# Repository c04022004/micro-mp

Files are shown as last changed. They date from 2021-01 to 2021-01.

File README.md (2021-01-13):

# Multi-purpose Arduino Micro shield

This is an attempt stuff functionalities onto an ATmega32U4-based board while keeping a moderate footprint and simple low-cost parts. The original version is made out of the necessity to replace dupont(jumper) wires for stability. The board gradually expanded into the current form. This is also my first few PCBs, so expect it to be less than optimal. I learnt a lot going through the design, soldering, debug process and enjoyed working on it.

## Functionalities/Devices
- 0.96'/1.3' OLED monitor
- RS485 thru MAX485
- Dual USB Serial (Native+CP2102)
- WS2812 LED, expandable, physical off SW
- EEPROM (ATMEL AT24C )
- PCF8574 I/O expansion (8 Pins)
- Type-C USB Power, fuse
- Buttons, Reset button
- IDC header (2x05) for external boards

## Renderings
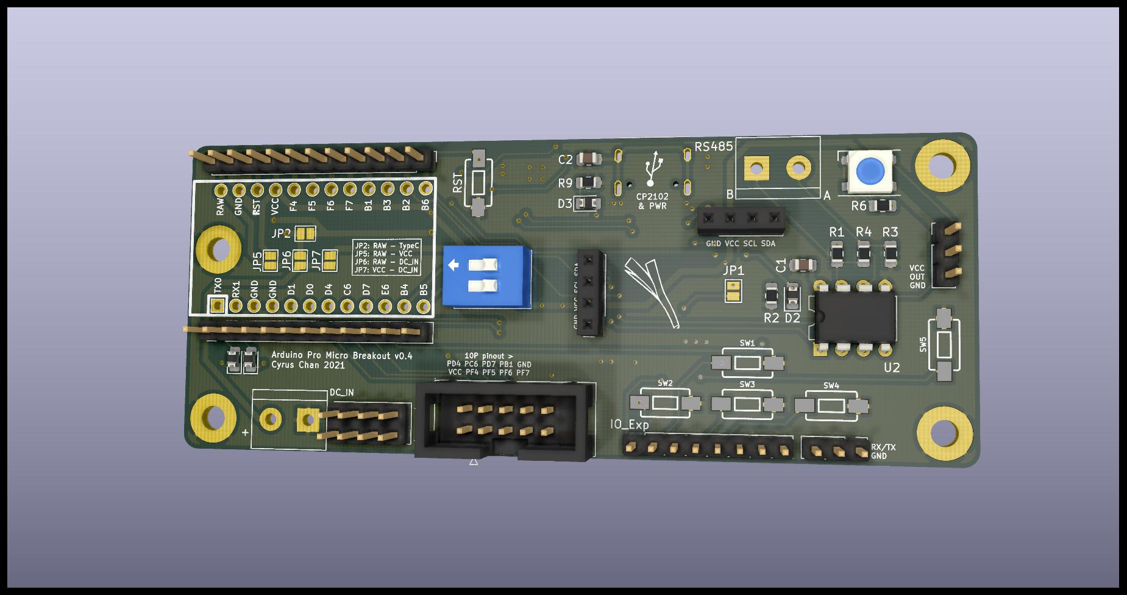
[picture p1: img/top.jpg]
Top Side

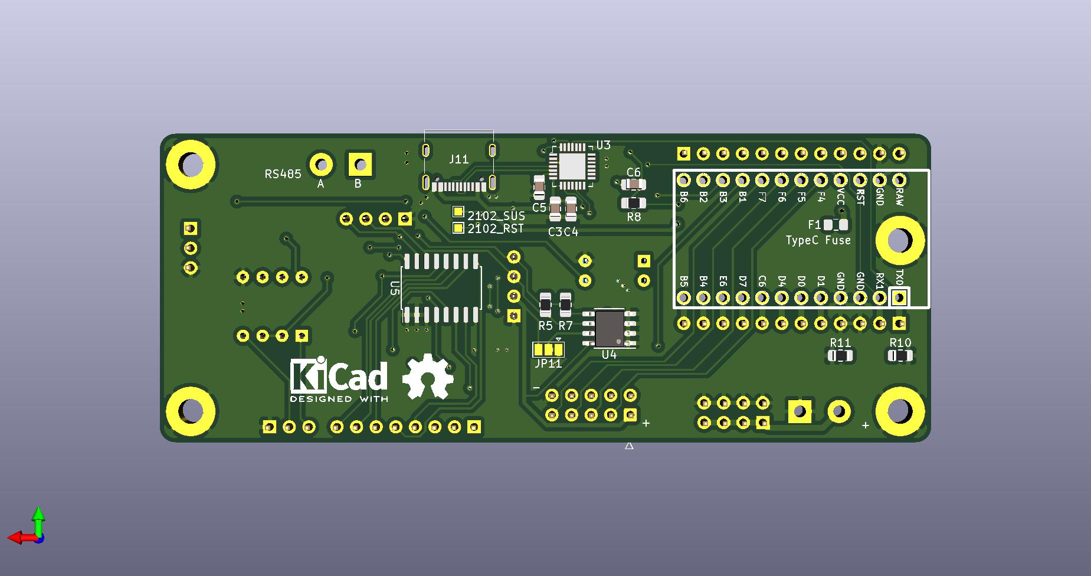
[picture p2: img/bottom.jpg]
Bottom Side


## Actual Hardware
Evolving Hardware:  
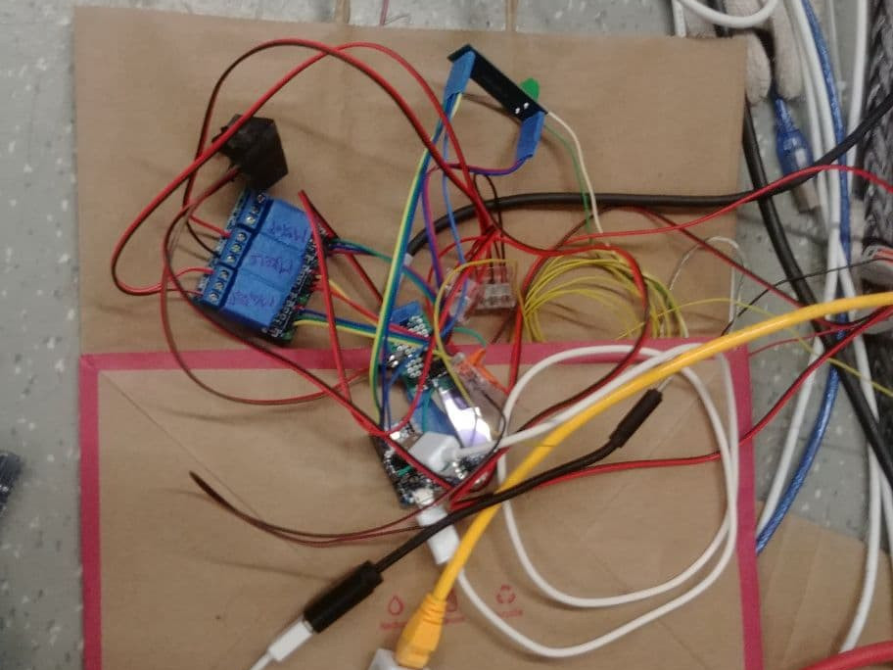
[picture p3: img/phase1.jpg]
Phase1

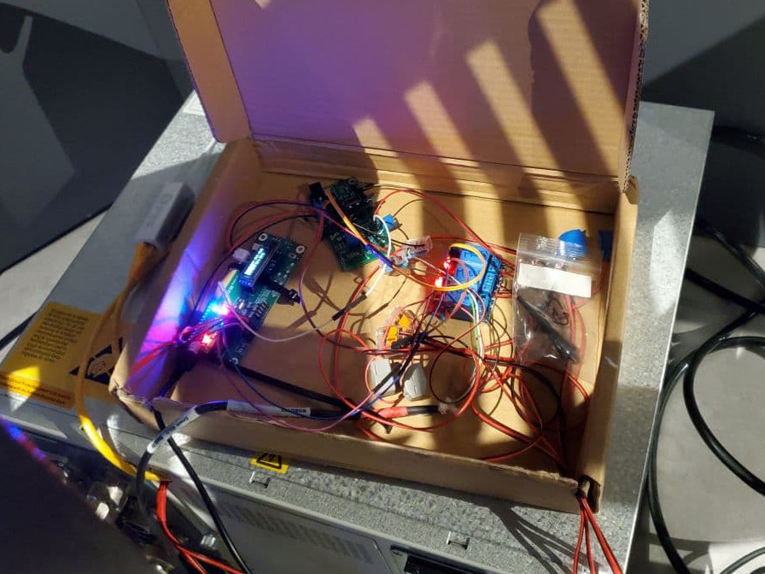
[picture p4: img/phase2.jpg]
Phase2

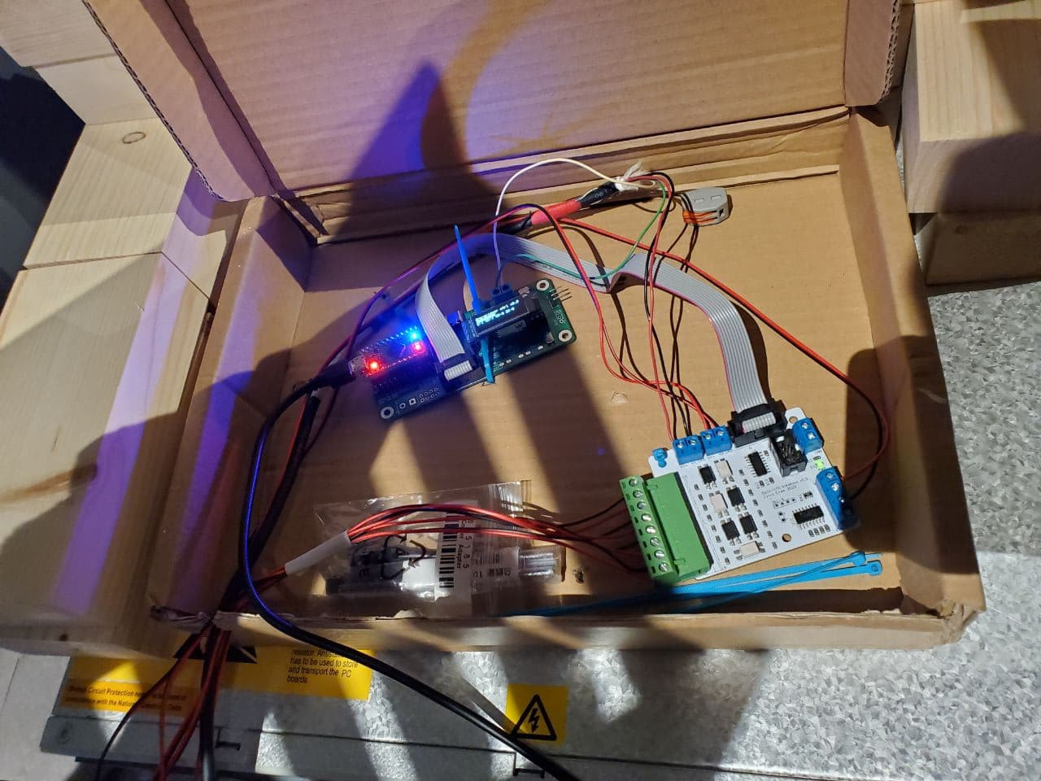
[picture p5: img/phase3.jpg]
Phase3


## Library Used
- https://github.com/keebio/keebio-components
- https://github.com/keebio/Keebio-Parts.pretty
- https://github.com/sparkfun/SparkFun-KiCad-Libraries
- https://github.com/Digi-Key/digikey-kicad-library

## To be constructed
- BOM
- Demo Images
- Extensions

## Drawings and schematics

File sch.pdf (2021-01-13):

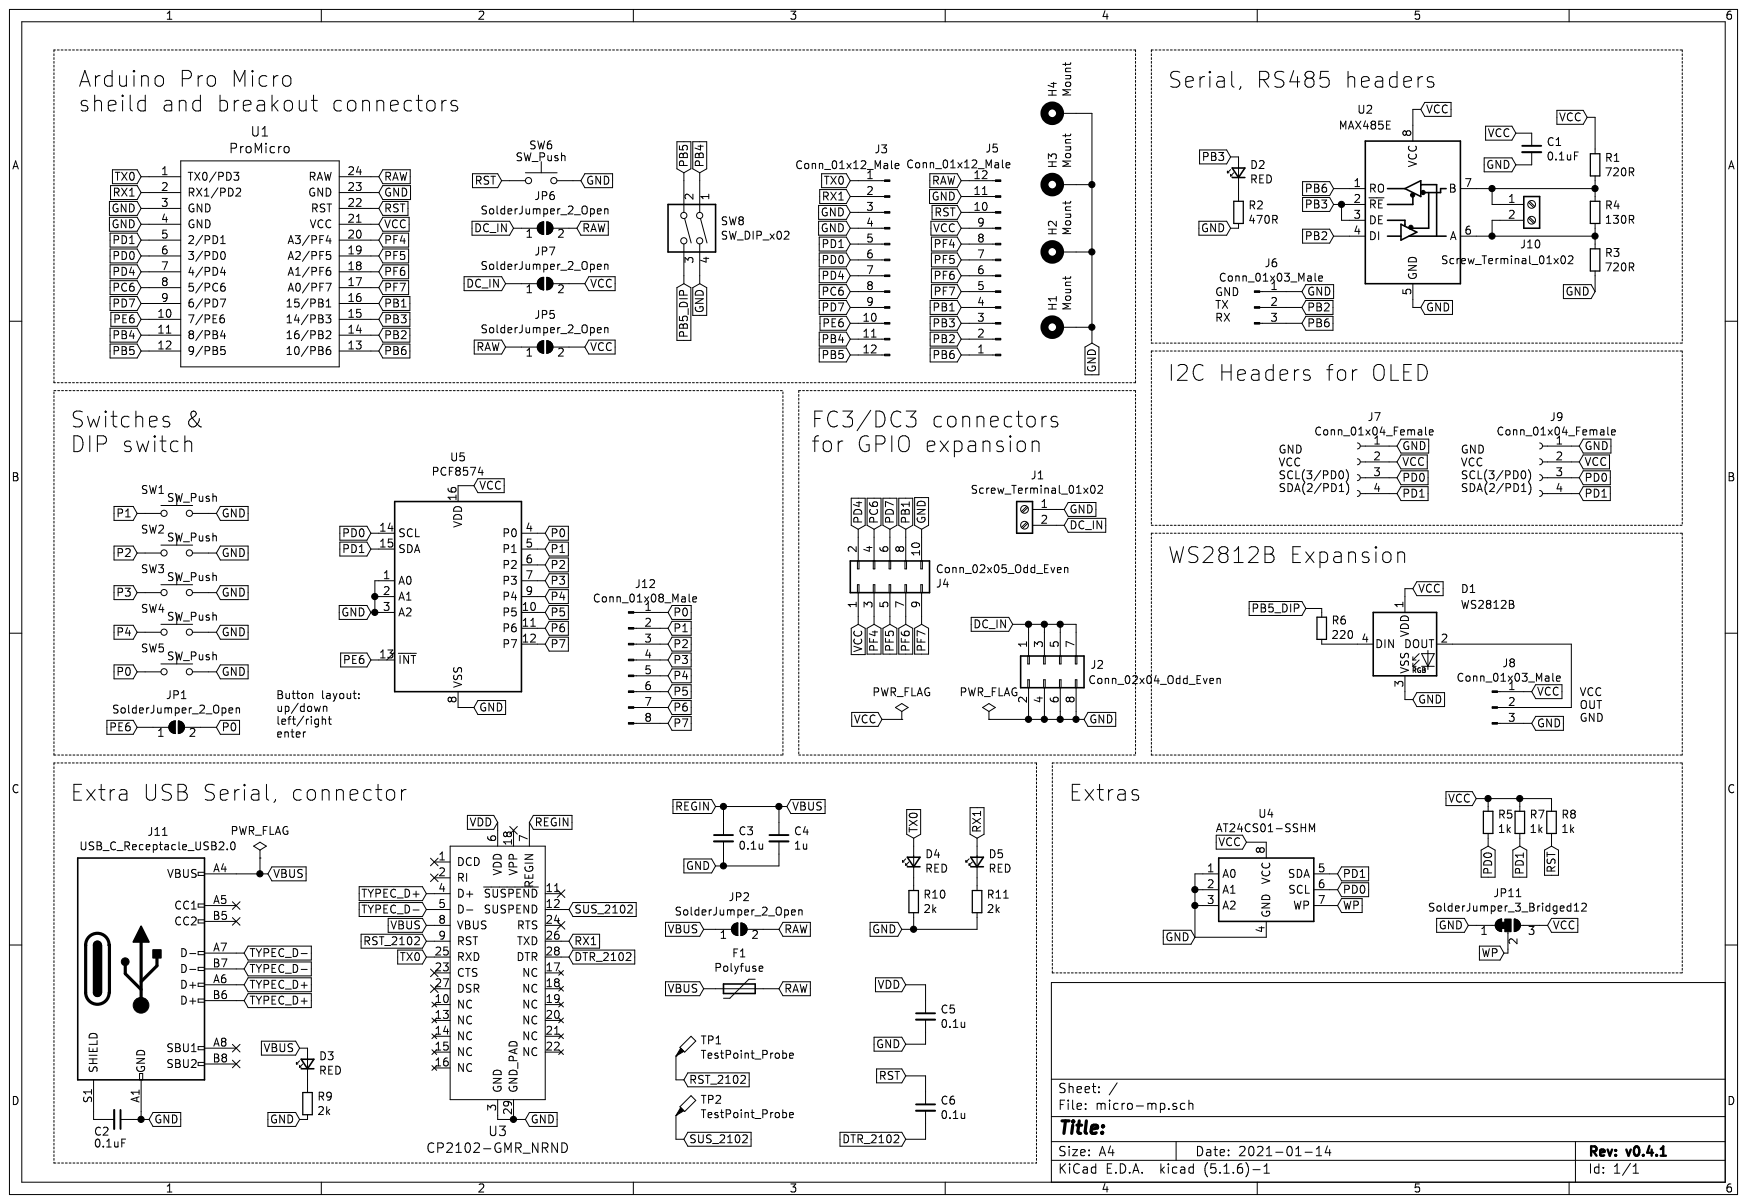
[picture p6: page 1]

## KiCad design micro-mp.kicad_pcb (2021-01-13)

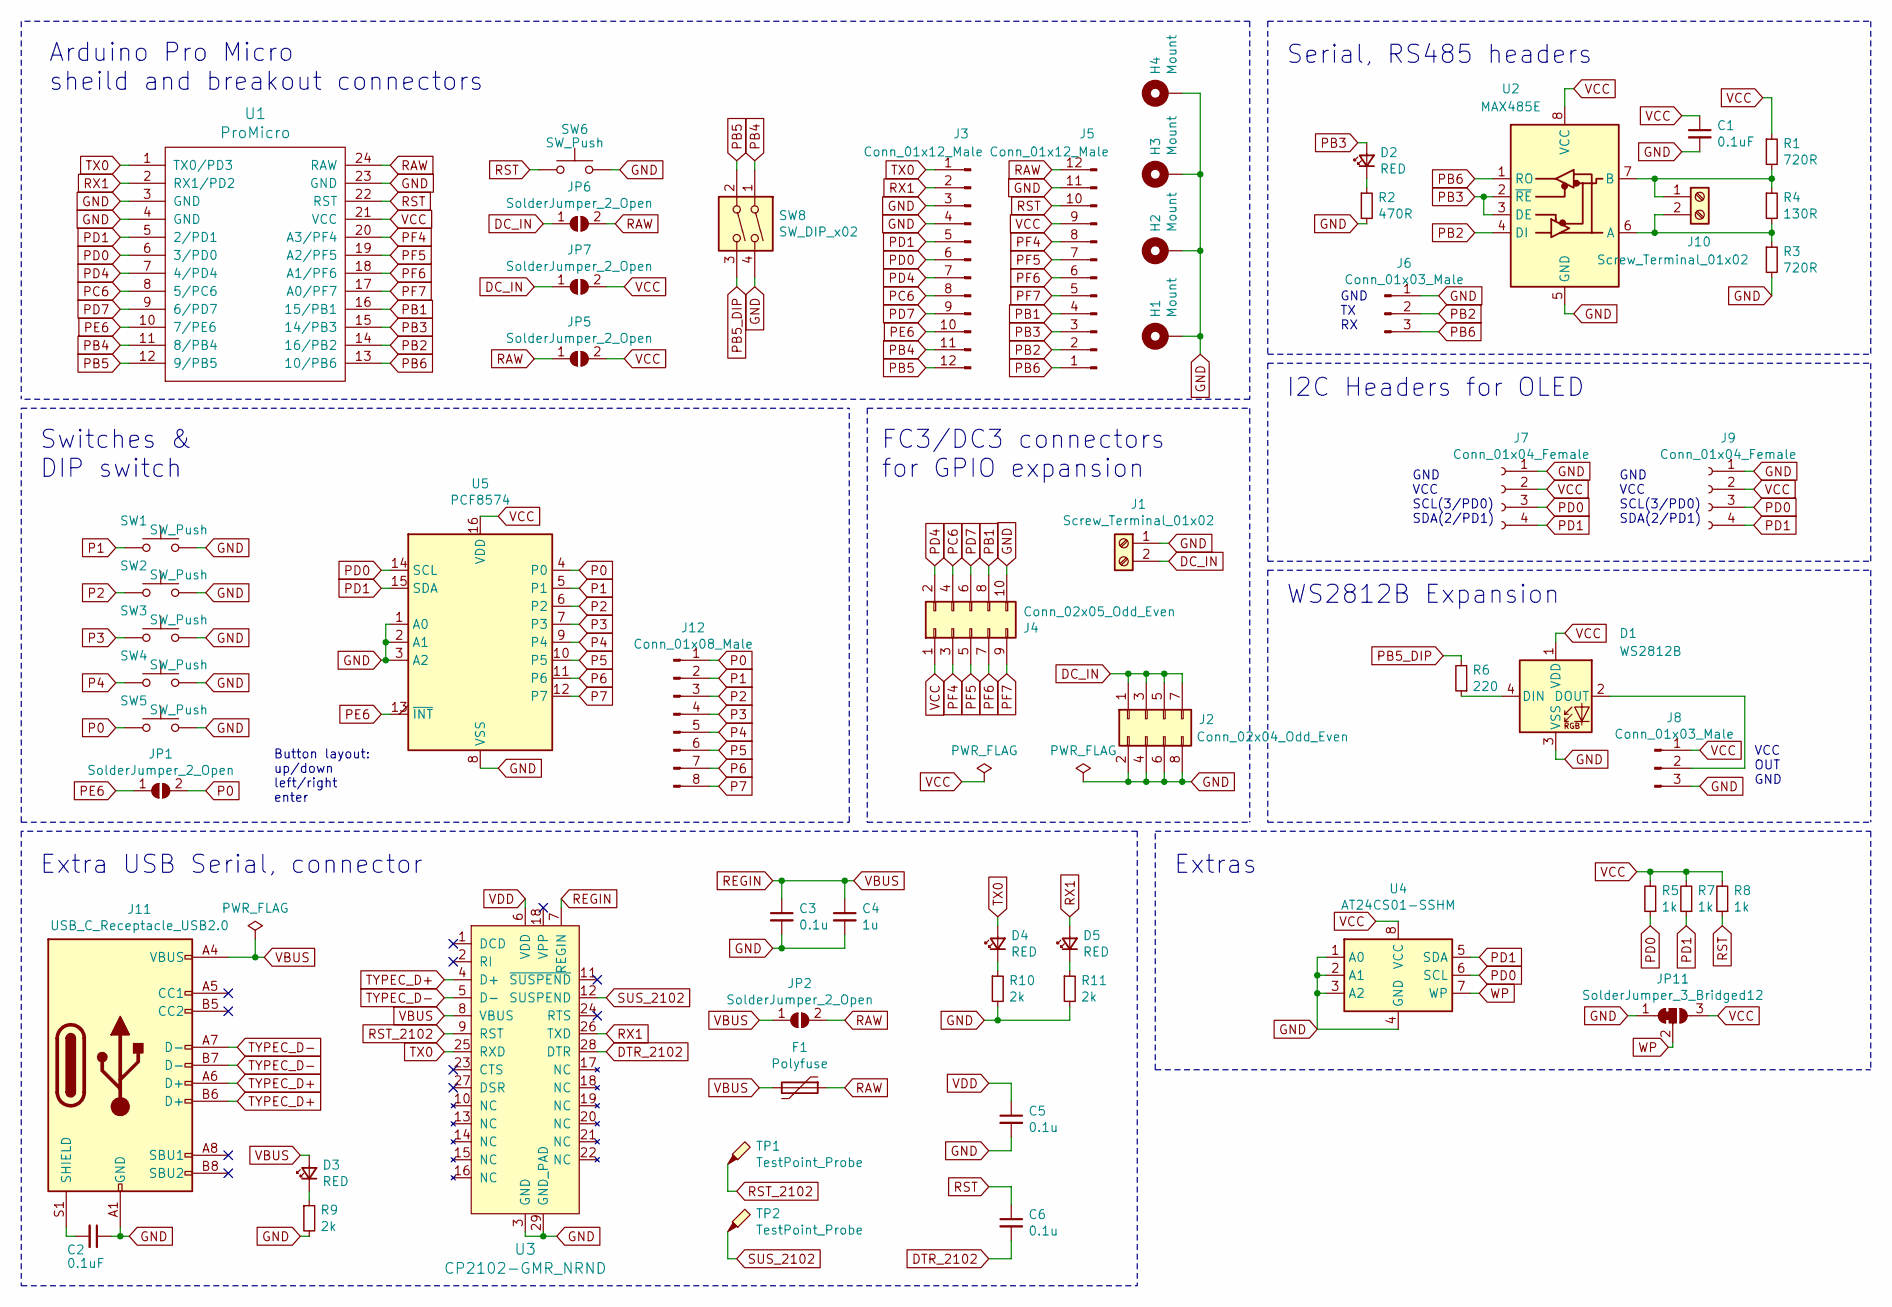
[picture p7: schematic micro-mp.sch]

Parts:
C1, C2: 0.1uF; C_0805_2012Metric_Pad1.15x1.40mm_HandSolder
C3, C5, C6: 0.1u; C_0805_2012Metric_Pad1.15x1.40mm_HandSolder
C4: 1u; C_0805_2012Metric_Pad1.15x1.40mm_HandSolder
D1: WS2812B; LED_WS2812B_PLCC4_5.0x5.0mm_P3.2mm
D2, D3, D4, D5: RED; D_0805_2012Metric_Pad1.15x1.40mm_HandSolder
F1: Polyfuse; Fuse_0805_2012Metric_Pad1.15x1.40mm_HandSolder
H1, H2, H3, H4: Mount; MountingHole_3.2mm_M3_Pad
J1, J10: Screw_Terminal_01x02; TerminalBlock_bornier-2_P5.08mm
J2: Conn_02x04_Odd_Even; PinHeader_2x04_P2.54mm_Vertical
J3, J5: Conn_01x12_Male; PinHeader_1x12_P2.54mm_Vertical
J4: Conn_02x05_Odd_Even; IDC-Header_2x05_P2.54mm_Vertical
J6, J8: Conn_01x03_Male; PinHeader_1x03_P2.54mm_Vertical
J7, J9: Conn_01x04_Female; PinSocket_1x04_P2.54mm_Vertical
J11: USB_C_Receptacle_USB2.0; USB_C_Receptacle_Palconn_UTC16-G
J12: Conn_01x08_Male; PinHeader_1x08_P2.54mm_Vertical
JP1, JP2, JP5, JP6, JP7: SolderJumper_2_Open; SolderJumper-2_P1.3mm_Open_Pad1.0x1.5mm
JP11: SolderJumper_3_Bridged12; SolderJumper-3_P1.3mm_Bridged12_Pad1.0x1.5mm
R1, R3: 720R; R_0805_2012Metric_Pad1.15x1.40mm_HandSolder
R2: 470R; R_0805_2012Metric_Pad1.15x1.40mm_HandSolder
R4: 130R; R_0805_2012Metric_Pad1.15x1.40mm_HandSolder
R5, R7, R8: 1k; R_0805_2012Metric_Pad1.15x1.40mm_HandSolder
R6: 220; R_0805_2012Metric_Pad1.15x1.40mm_HandSolder
R9, R10, R11: 2k; R_0805_2012Metric_Pad1.15x1.40mm_HandSolder
SW1, SW2, SW3, SW4, SW5, SW6: SW_Push; TACTILE_SWITCH_SMD_6.0X3.5MM
SW8: SW_DIP_x02; SW_DIP_SPSTx02_Slide_9.78x7.26mm_W7.62mm_P2.54mm
TP1, TP2: TestPoint_Probe; TestPoint_Pad_1.0x1.0mm
U1: ProMicro; ArduinoProMicro
U2: MAX485E; DIP-8_W7.62mm
U3: CP2102-GMR_NRND; VFQFN-28-1EP_5x5mm; MPN CP2102-GMR; Digi-Key_PN 336-1160-1-ND
U4: AT24CS01-SSHM; SOIC-8_3.9x4.9mm_P1.27mm
U5: PCF8574; SO-16_5.3x10.2mm_P1.27mm

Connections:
DC_IN: J1.2, J2.1, J2.3, J2.5, J2.7, JP6.1 (A), JP7.1 (A)
DTR_2102: C6.2, U3.28 (DTR)
GND: C1.2, C2.1, C3.2, C4.2, C5.2, D1.3 (VSS), H1.1, H2.1, H3.1, H4.1, J1.1, J2.2, J2.4, J2.6, J2.8, J3.3, J3.4, J4.10, J5.11, J6.1, J7.1, J8.3, J9.1, J11.A1 (GND), J11.A12 (GND), J11.B1 (GND), J11.B12 (GND), JP11.1 (A), R2.2, R3.2, R9.2, R10.2, R11.2, SW1.2, SW2.2, SW3.2, SW4.2, SW5.2, SW6.2, SW8.4, U1.3 (GND), U1.4 (GND), U1.23 (GND), U2.5 (GND), U3.3 (GND), U3.29 (GND_PAD), U4.1 (A0), U4.2 (A1), U4.3 (A2), U4.4 (GND), U5.1 (A0), U5.2 (A1), U5.3 (A2), U5.8 (VSS)
unnamed: C2.2, J11.S1 (SHIELD)
unnamed: D1.2 (DOUT), J8.2
unnamed: D1.4 (DIN), R6.1
unnamed: D2.1 (K), R2.1
unnamed: D3.1 (K), R9.1
unnamed: D4.1 (K), R10.1
unnamed: D5.1 (K), R11.1
unnamed: J10.1, R1.2, R4.1, U2.7 (B)
unnamed: J10.2, R3.1, R4.2, U2.6 (A)
P0: J12.1, JP1.2 (B), SW5.1, U5.4 (P0)
P1: J12.2, SW1.1, U5.5 (P1)
P2: J12.3, SW2.1, U5.6 (P2)
P3: J12.4, SW3.1, U5.7 (P3)
P4: J12.5, SW4.1, U5.9 (P4)
P5: J12.6, U5.10 (P5)
P6: J12.7, U5.11 (P6)
P7: J12.8, U5.12 (P7)
PB1: J4.8, J5.4, U1.16 (15/PB1)
PB2: J5.2, J6.2, U1.14 (16/PB2), U2.4 (DI)
PB3: D2.2 (A), J5.3, U1.15 (14/PB3), U2.2 (~RE), U2.3 (DE)
PB4: J3.11, SW8.1, U1.11 (8/PB4)
PB5: J3.12, SW8.2, U1.12 (9/PB5)
PB5_DIP: R6.2, SW8.3
PB6: J5.1, J6.3, U1.13 (10/PB6), U2.1 (RO)
PC6: J3.8, J4.4, U1.8 (5/PC6)
PD0: J3.6, J7.3, J9.3, R5.1, U1.6 (3/PD0), U4.6 (SCL), U5.14 (SCL)
PD1: J3.5, J7.4, J9.4, R7.1, U1.5 (2/PD1), U4.5 (SDA), U5.15 (SDA)
PD4: J3.7, J4.2, U1.7 (4/PD4)
PD7: J3.9, J4.6, U1.9 (6/PD7)
PE6: J3.10, JP1.1 (A), U1.10 (7/PE6), U5.13 (~INT~)
PF4: J4.3, J5.8, U1.20 (A3/PF4)
PF5: J4.5, J5.7, U1.19 (A2/PF5)
PF6: J4.7, J5.6, U1.18 (A1/PF6)
PF7: J4.9, J5.5, U1.17 (A0/PF7)
RAW: F1.1, J5.12, JP2.2 (B), JP5.1 (A), JP6.2 (B), U1.24 (RAW)
REGIN: C3.1, C4.1, D3.2 (A), F1.2, J11.A4 (VBUS), J11.A9 (VBUS), J11.B4 (VBUS), J11.B9 (VBUS), JP2.1 (A), U3.7 (REGIN), U3.8 (VBUS)
RST: C6.1, J5.10, R8.1, SW6.1, U1.22 (RST)
RST_2102: TP1.1, U3.9 (RST)
RX1: D5.2 (A), J3.2, U1.2 (RX1/PD2), U3.26 (TXD)
SUS_2102: TP2.1, U3.12 (SUSPEND)
TX0: D4.2 (A), J3.1, U1.1 (TX0/PD3), U3.25 (RXD)
TYPEC_D+: J11.A6 (D+), J11.B6 (D+), U3.4 (D+)
TYPEC_D-: J11.A7 (D-), J11.B7 (D-), U3.5 (D-)
VCC: C1.1, D1.1 (VDD), J4.1, J5.9, J7.2, J8.1, J9.2, JP5.2 (B), JP7.2 (B), JP11.3 (B), R1.1, R5.2, R7.2, R8.2, U1.21 (VCC), U2.8 (VCC), U4.8 (VCC), U5.16 (VDD)
VDD: C5.1, U3.6 (VDD)
WP: JP11.2 (C), U4.7 (WP)

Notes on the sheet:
GND TX RX
GND VCC SCL(3/PD0) SDA(2/PD1)
Button layout: up/down left/right enter
Serial, RS485 headers
I2C Headers for OLED
Extra USB Serial, connector
VCC OUT GND
WS2812B Expansion
Switches & DIP switch
Arduino Pro Micro sheild and breakout connectors
FC3/DC3 connectors for GPIO expansion
Extras

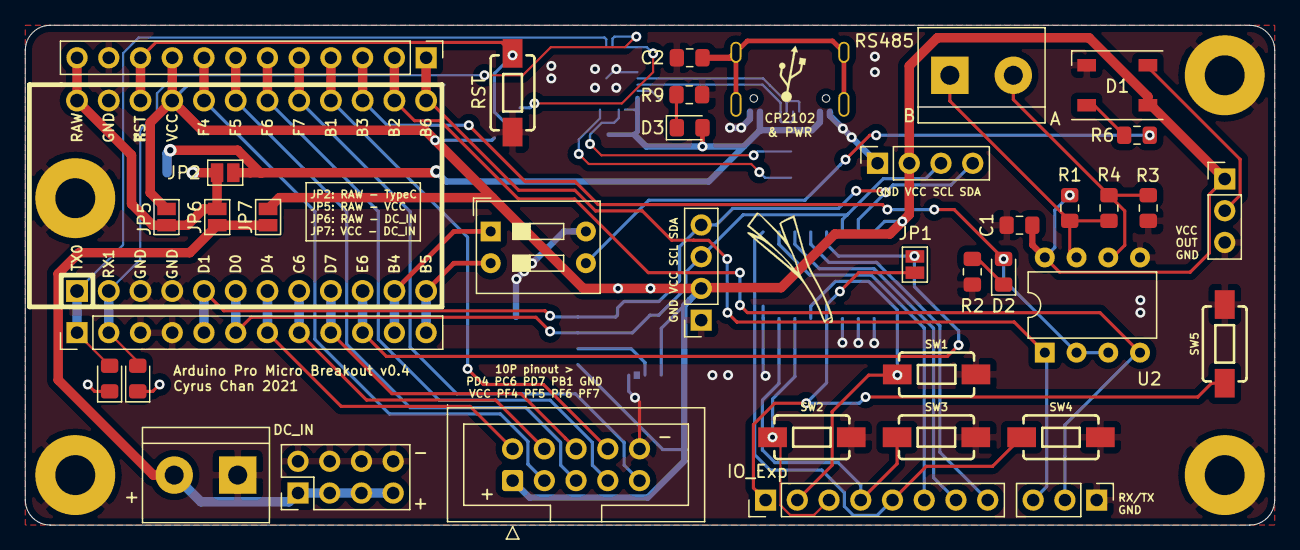
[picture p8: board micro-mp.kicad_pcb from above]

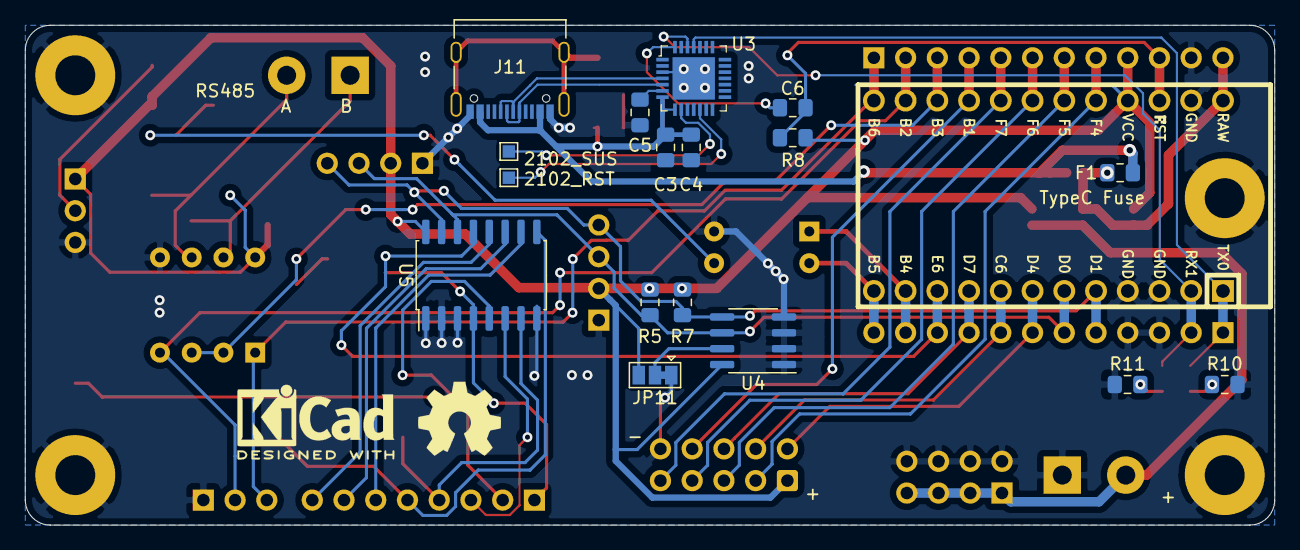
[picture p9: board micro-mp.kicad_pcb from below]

Board: 2 copper layers, 100.0 x 40.0 mm, 59 parts (17 on the bottom side), 49 nets.
